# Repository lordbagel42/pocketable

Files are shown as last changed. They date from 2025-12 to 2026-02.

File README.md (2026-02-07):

# Pocketable

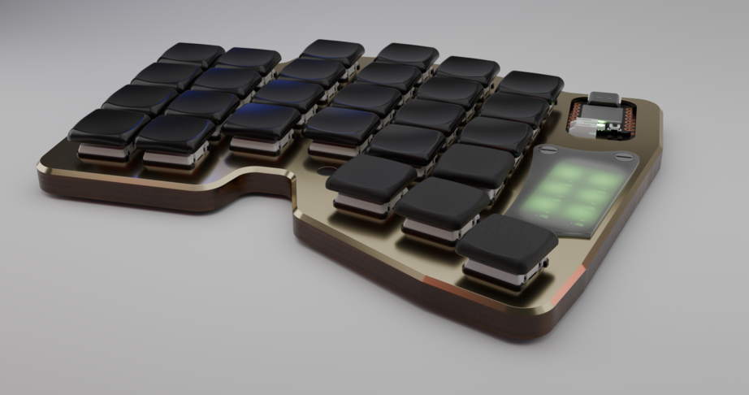
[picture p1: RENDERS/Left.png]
keyboard left half

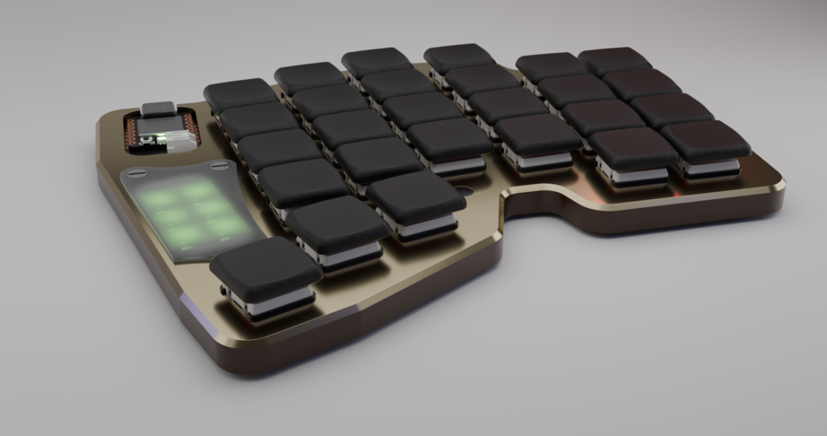
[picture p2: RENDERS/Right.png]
keyboard right half


<sup><sub>ignore the fact that some of the keycaps are shiny and others are matte. blender is not happy with me.</sub></sup>

if a corne and a zsa voyager had a child\_

This project was made for one primary reason: my old split keyboard design kinda sucked to make layouts for. The thumb cluster was horrible. This, however, will function with ZSA Voyager layouts, which are generally shared publicly and well-tested.

This will be for sale eventually. Please reply to [issue 1](https://github.com/lordbagel42/pocketable/issues/1) if you would like to buy one. Cost will be around $240 per keyboard.

## but why?

This keyboards a little special compared to most, for one reason: it's almost all made in-house by me. I'll be machining the brass plate myself along with the wooden base case, plus laser-cutting the acrylic LED cover myself. It's also all hand soldered and one day will have custom keycaps. For now though I've been graciously sponsored with black keycaps.

# BOM

View the BOM at [this google sheet](https://docs.google.com/spreadsheets/d/1JvyBpCuiH7XgFo-gO215HGFeqtSEhnPSUs8fcJy509Q/edit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). Total cost at time of writing this README is ~$250

## more photos :3

heres the pcb design!

silkscreen art will be included for mine, however I won't be showing it in this repo as it contains a lil PII :3

le pcb

## left half schematic



## right half schematic



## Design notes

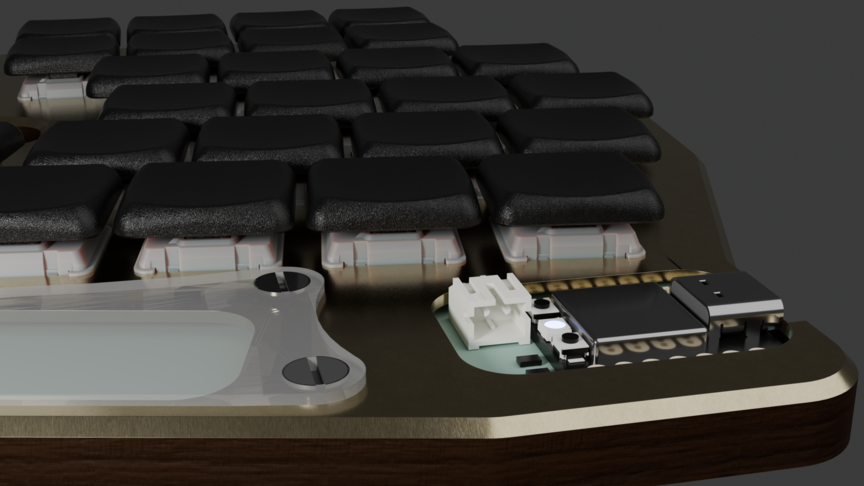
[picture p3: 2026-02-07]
RENDERS/thing.png

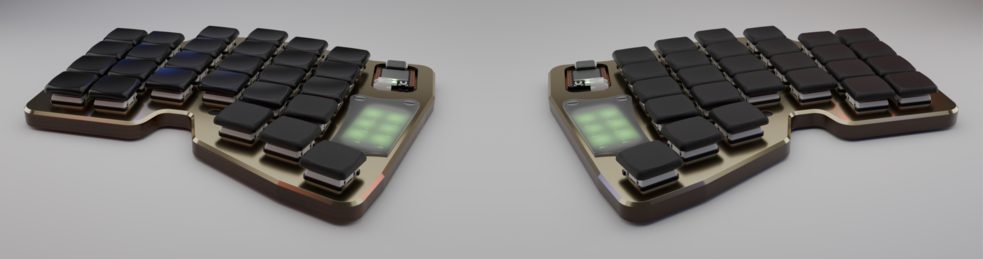
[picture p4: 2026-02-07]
RENDERS/Both maybe.png

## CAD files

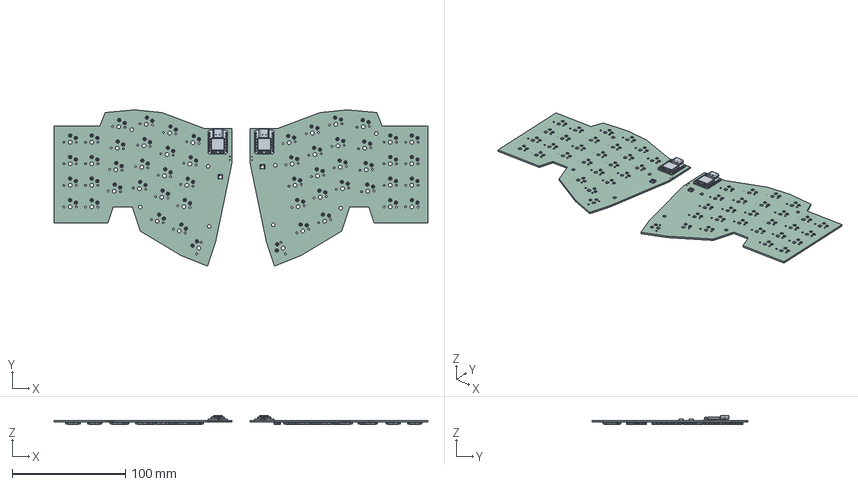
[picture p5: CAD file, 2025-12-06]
PCB/split-keeb-v2.step
330.5 x 138.1 x 8.04 mm
split-keeb-v2 1.1.1 x 2
CON_BM02B-ACHSS x 2
pin x 108
socket x 54
split-keeb-v2_PCB_1
split-keeb-v2_PCB_2

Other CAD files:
CAD/Case Thing.step
MODELS/SOD123_MCC.step
RENDER-FILES/Pocketable.obj
split-keeb-v2-render-edition.step
RENDER-FILES/Render.blend
RENDER-FILES/Render2.blend
RENDER-FILES/Untitled.blend
RENDER-FILES/assets/materials/acrylic_564227e0-b76e-4f32-97c1-0bfcf024c71d/acrylic_405d28f9-2327-4cdb-8ebe-de592a518881.blend
RENDER-FILES/assets/materials/black-plastic_5d077501-2739-44eb-8ed7-a99897d95238/black-plastic_2K_d53818b9-7dfc-4b44-ac51-068fa59820db.blend
RENDER-FILES/assets/materials/black-plastic_e872536a-48ed-4424-ac7b-80dc008e9748/black-plastic_2K_c94cf275-089d-43ee-92c3-5c641194570c.blend
RENDER-FILES/assets/materials/brushed-aluminum_44023395-1cd7-4842-a408-5d7ac18a4476/brushed-aluminum-2_b89e08f7-2682-4f2b-bb34-63eb4a2919d5.blend
RENDER-FILES/assets/materials/brushed-brass_9859c06d-0575-429e-a010-a8d801173d15/brushed-brass_2K_836541c2-a90c-42f0-bd5b-efe868081672.blend
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

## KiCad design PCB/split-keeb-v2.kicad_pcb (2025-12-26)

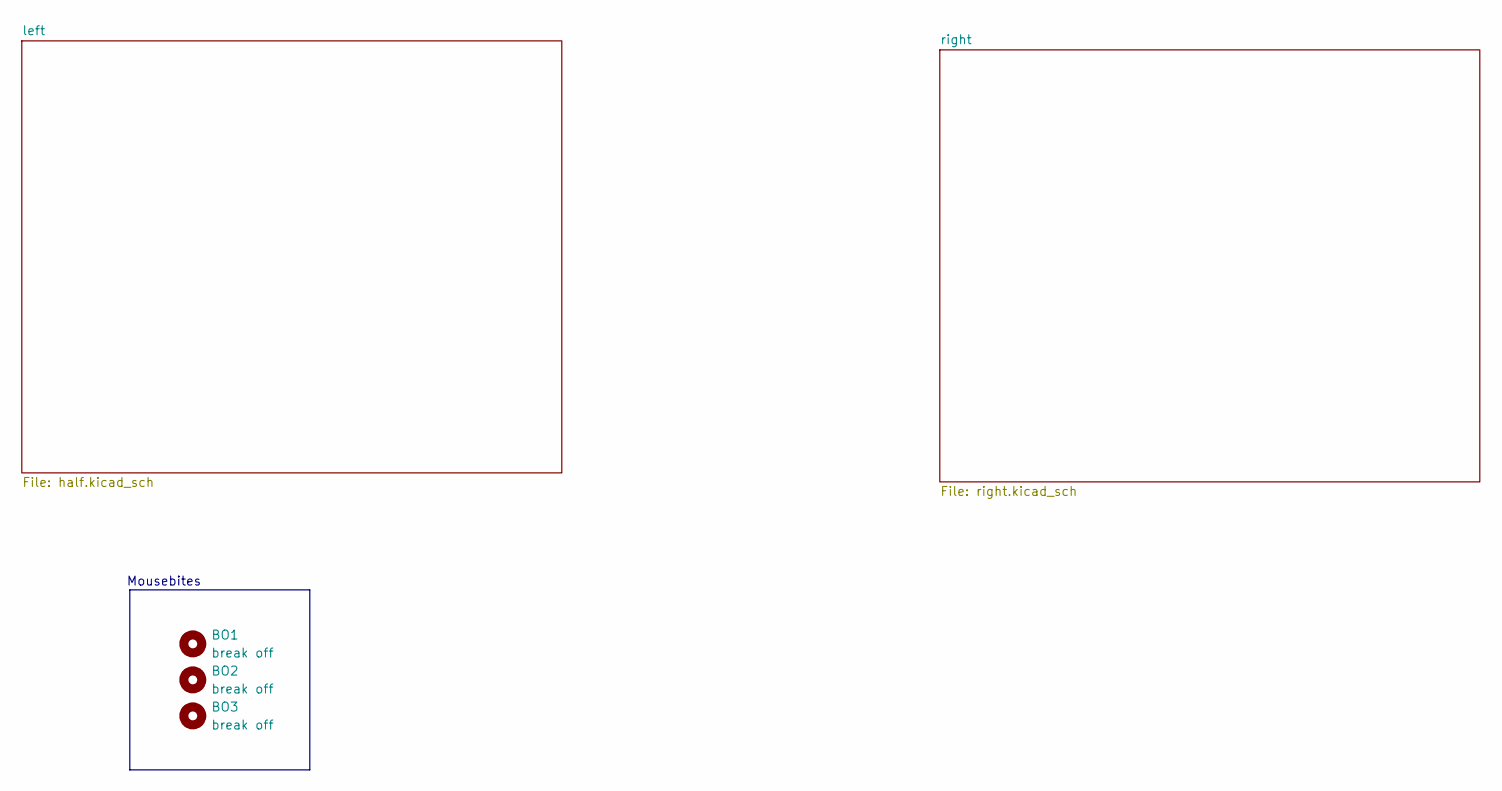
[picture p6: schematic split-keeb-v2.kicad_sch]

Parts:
BO1, BO2, BO3: break off; mouse-bite-5mm-slot

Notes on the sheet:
Mousebites

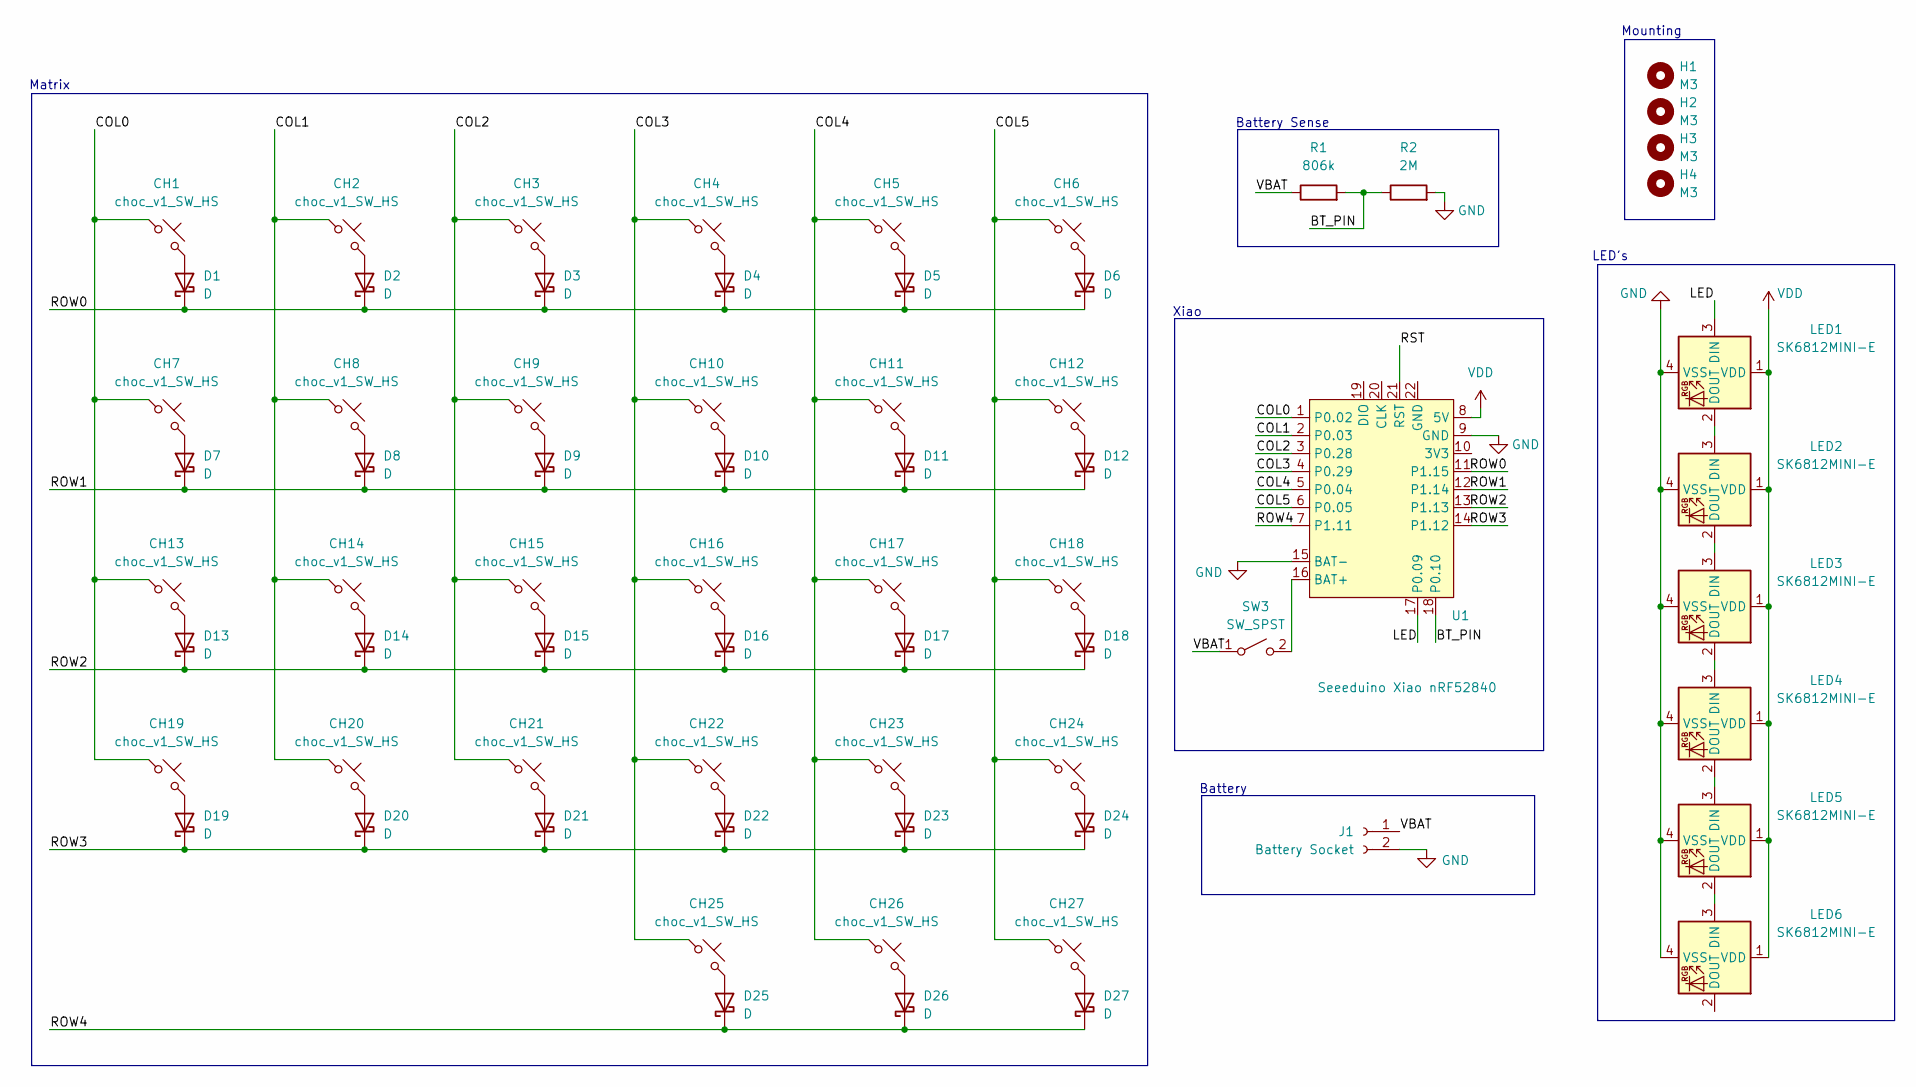
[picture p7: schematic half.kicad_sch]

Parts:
CH1, CH2, CH3, CH4, CH5, CH6, CH7, CH8, CH9, CH10, CH11, CH12, CH13, CH14, CH15, CH16, CH17, CH18, CH19, CH20, CH21, CH22, CH23, CH24, CH25, CH26, CH27: choc_v1_SW_HS; SW_choc_v1_HS_CPG135001S30_1u
D1, D2, D3, D4, D5, D6, D7, D8, D9, D10, D11, D12, D13, D14, D15, D16, D17, D18, D19, D20, D21, D22, D23, D24, D25, D26, D27: D; D_SOD-123
H1, H2, H3, H4: M3; MountingHole_3.2mm_M3
J1: Battery Socket; CON_JST_ACH_BM02B
LED1, LED2, LED3, LED4, LED5, LED6: SK6812MINI-E; LED_6028R
R1: 806k; R_0805_2012Metric
R2: 2M; R_0805_2012Metric
SW3: SW_SPST; SW_SPDT_PCM12
U1: Seeeduino Xiao nRF52840; Xiao_nRF52840_ACH

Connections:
/left/BT_PIN: R1.2, R2.1, U1.18 (P0.10)
/left/COL0: CH1.1, CH7.1, CH13.1, CH19.1, U1.1 (P0.02)
/left/COL1: CH2.1, CH8.1, CH14.1, CH20.1, U1.2 (P0.03)
/left/COL2: CH3.1, CH9.1, CH15.1, CH21.1, U1.3 (P0.28)
/left/COL3: CH4.1, CH10.1, CH16.1, CH22.1, CH25.1, U1.4 (P0.29)
/left/COL4: CH5.1, CH11.1, CH17.1, CH23.1, CH26.1, U1.5 (P0.04)
/left/COL5: CH6.1, CH12.1, CH18.1, CH24.1, CH27.1, U1.6 (P0.05)
/left/LED: LED1.3 (DIN), U1.17 (P0.09)
/left/ROW0: D1.1 (K), D2.1 (K), D3.1 (K), D4.1 (K), D5.1 (K), D6.1 (K), U1.11 (P1.15)
/left/ROW1: D7.1 (K), D8.1 (K), D9.1 (K), D10.1 (K), D11.1 (K), D12.1 (K), U1.12 (P1.14)
/left/ROW2: D13.1 (K), D14.1 (K), D15.1 (K), D16.1 (K), D17.1 (K), D18.1 (K), U1.13 (P1.13)
/left/ROW3: D19.1 (K), D20.1 (K), D21.1 (K), D22.1 (K), D23.1 (K), D24.1 (K), U1.14 (P1.12)
/left/ROW4: D25.1 (K), D26.1 (K), D27.1 (K), U1.7 (P1.11)
/left/RST: U1.21 (RST)
/left/VBAT: J1.1, R1.1, SW3.1 (A)
GND: J1.2, LED1.4 (VSS), LED2.4 (VSS), LED3.4 (VSS), LED4.4 (VSS), LED5.4 (VSS), LED6.4 (VSS), R2.2, U1.9 (GND), U1.15 (BAT-); also elsewhere on the board
unnamed: CH1.2, D1.2 (A)
unnamed: CH2.2, D2.2 (A)
unnamed: CH3.2, D3.2 (A)
unnamed: CH4.2, D4.2 (A)
unnamed: CH5.2, D5.2 (A)
unnamed: CH6.2, D6.2 (A)
unnamed: CH7.2, D7.2 (A)
unnamed: CH8.2, D8.2 (A)
unnamed: CH9.2, D9.2 (A)
unnamed: CH10.2, D10.2 (A)
unnamed: CH11.2, D11.2 (A)
unnamed: CH12.2, D12.2 (A)
unnamed: CH13.2, D13.2 (A)
unnamed: CH14.2, D14.2 (A)
unnamed: CH15.2, D15.2 (A)
unnamed: CH16.2, D16.2 (A)
unnamed: CH17.2, D17.2 (A)
unnamed: CH18.2, D18.2 (A)
unnamed: CH19.2, D19.2 (A)
unnamed: CH20.2, D20.2 (A)
unnamed: CH21.2, D21.2 (A)
unnamed: CH22.2, D22.2 (A)
unnamed: CH23.2, D23.2 (A)
unnamed: CH24.2, D24.2 (A)
unnamed: CH25.2, D25.2 (A)
unnamed: CH26.2, D26.2 (A)
unnamed: CH27.2, D27.2 (A)
unnamed: LED1.2 (DOUT), LED2.3 (DIN)
unnamed: LED2.2 (DOUT), LED3.3 (DIN)
unnamed: LED3.2 (DOUT), LED4.3 (DIN)
unnamed: LED4.2 (DOUT), LED5.3 (DIN)
unnamed: LED5.2 (DOUT), LED6.3 (DIN)
unnamed: SW3.2 (B), U1.16 (BAT+)
VDD: LED1.1 (VDD), LED2.1 (VDD), LED3.1 (VDD), LED4.1 (VDD), LED5.1 (VDD), LED6.1 (VDD), U1.8 (5V); also elsewhere on the board

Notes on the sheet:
Battery Sense
Xiao
LED's
Mounting
Battery
Matrix

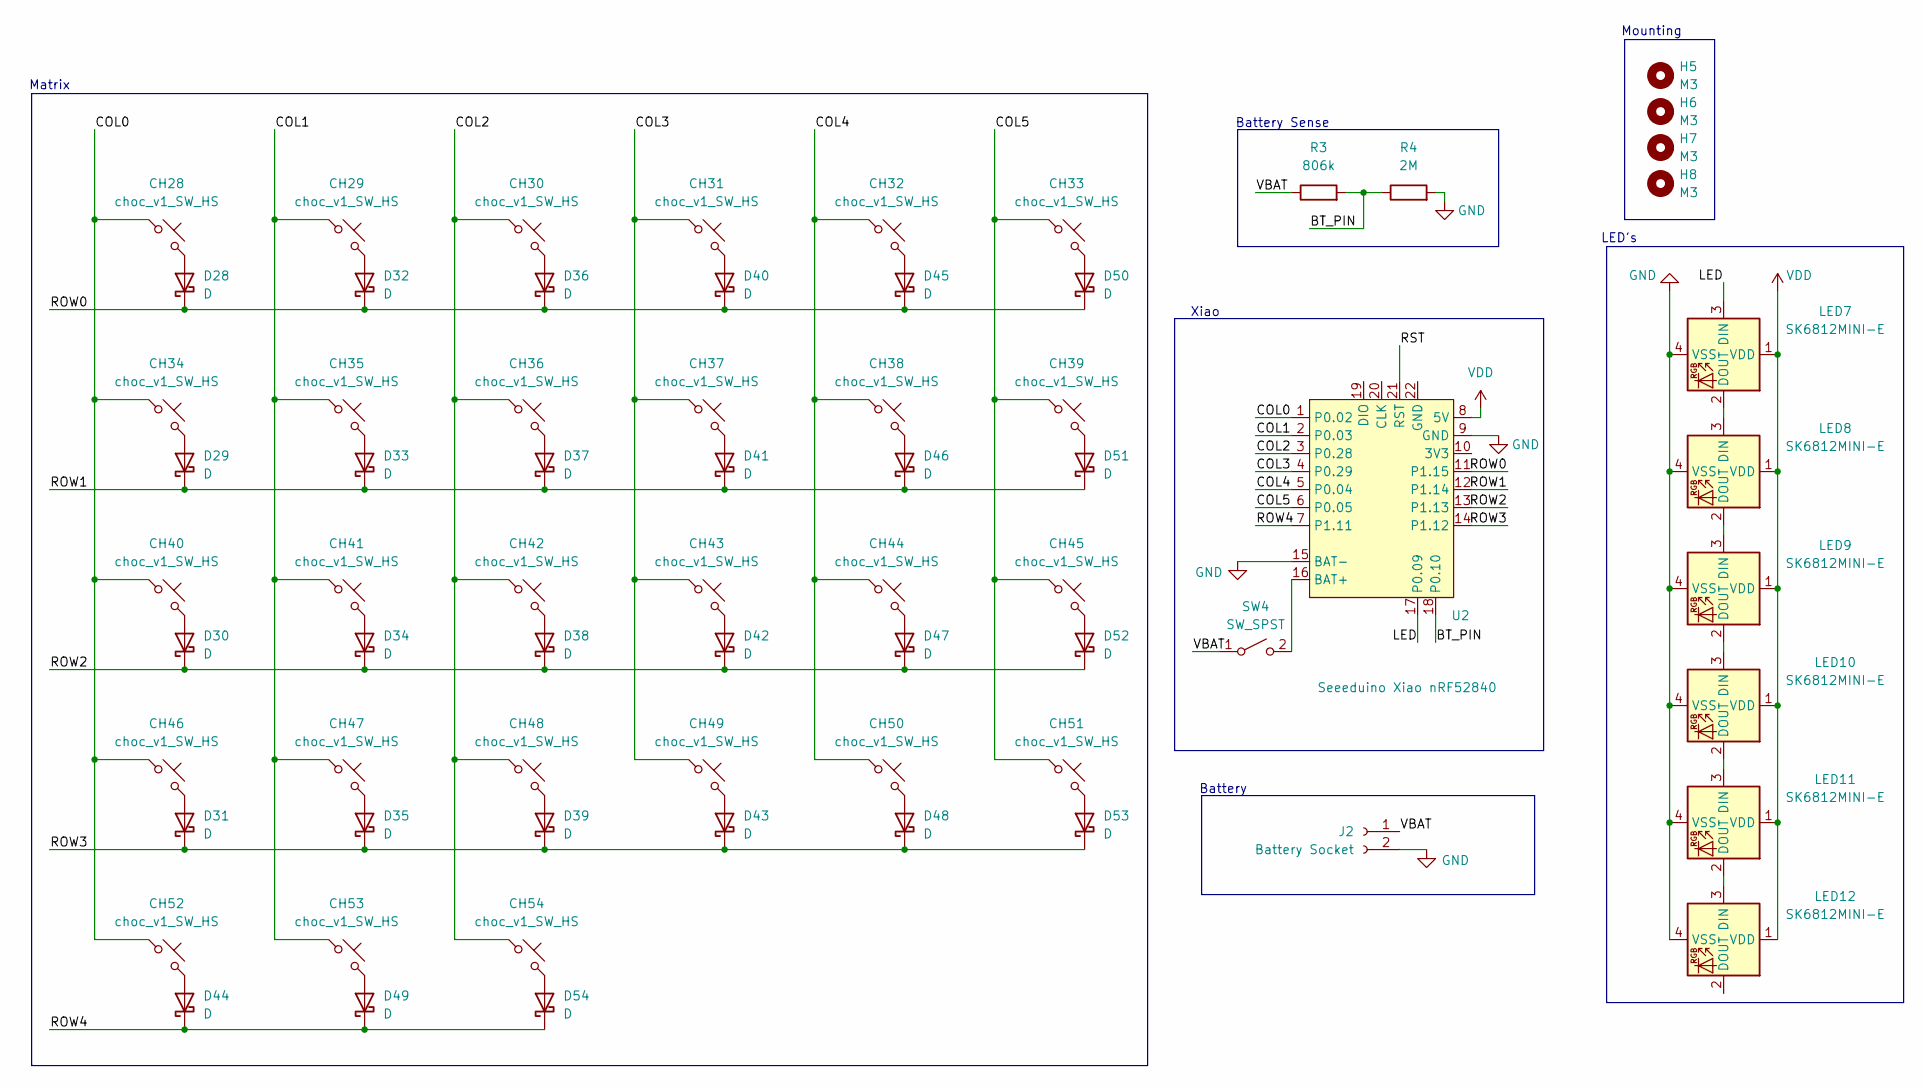
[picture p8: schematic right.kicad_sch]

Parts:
CH28, CH29, CH30, CH31, CH32, CH33, CH34, CH35, CH36, CH37, CH38, CH39, CH40, CH41, CH42, CH43, CH44, CH45, CH46, CH47, CH48, CH49, CH50, CH51, CH52, CH53, CH54: choc_v1_SW_HS; SW_choc_v1_HS_CPG135001S30_1u
D28, D29, D30, D31, D32, D33, D34, D35, D36, D37, D38, D39, D40, D41, D42, D43, D44, D45, D46, D47, D48, D49, D50, D51, D52, D53, D54: D; D_SOD-123
H5, H6, H7, H8: M3; MountingHole_3.2mm_M3
J2: Battery Socket; CON_JST_ACH_BM02B
LED7, LED8, LED9, LED10, LED11, LED12: SK6812MINI-E; LED_6028R
R3: 806k; R_0805_2012Metric
R4: 2M; R_0805_2012Metric
SW4: SW_SPST; SW_SPDT_PCM12
U2: Seeeduino Xiao nRF52840; Xiao_nRF52840_ACH

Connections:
/right/BT_PIN: R3.2, R4.1, U2.18 (P0.10)
/right/COL0: CH28.1, CH34.1, CH40.1, CH46.1, CH52.1, U2.1 (P0.02)
/right/COL1: CH29.1, CH35.1, CH41.1, CH47.1, CH53.1, U2.2 (P0.03)
/right/COL2: CH30.1, CH36.1, CH42.1, CH48.1, CH54.1, U2.3 (P0.28)
/right/COL3: CH31.1, CH37.1, CH43.1, CH49.1, U2.4 (P0.29)
/right/COL4: CH32.1, CH38.1, CH44.1, CH50.1, U2.5 (P0.04)
/right/COL5: CH33.1, CH39.1, CH45.1, CH51.1, U2.6 (P0.05)
/right/LED: LED7.3 (DIN), U2.17 (P0.09)
/right/ROW0: D28.1 (K), D32.1 (K), D36.1 (K), D40.1 (K), D45.1 (K), D50.1 (K), U2.11 (P1.15)
/right/ROW1: D29.1 (K), D33.1 (K), D37.1 (K), D41.1 (K), D46.1 (K), D51.1 (K), U2.12 (P1.14)
/right/ROW2: D30.1 (K), D34.1 (K), D38.1 (K), D42.1 (K), D47.1 (K), D52.1 (K), U2.13 (P1.13)
/right/ROW3: D31.1 (K), D35.1 (K), D39.1 (K), D43.1 (K), D48.1 (K), D53.1 (K), U2.14 (P1.12)
/right/ROW4: D44.1 (K), D49.1 (K), D54.1 (K), U2.7 (P1.11)
/right/RST: U2.21 (RST)
/right/VBAT: J2.1, R3.1, SW4.1 (A)
GND: J2.2, LED7.4 (VSS), LED8.4 (VSS), LED9.4 (VSS), LED10.4 (VSS), LED11.4 (VSS), LED12.4 (VSS), R4.2, U2.9 (GND), U2.15 (BAT-); also elsewhere on the board
unnamed: CH28.2, D28.2 (A)
unnamed: CH34.2, D29.2 (A)
unnamed: CH40.2, D30.2 (A)
unnamed: CH46.2, D31.2 (A)
unnamed: CH29.2, D32.2 (A)
unnamed: CH35.2, D33.2 (A)
unnamed: CH41.2, D34.2 (A)
unnamed: CH47.2, D35.2 (A)
unnamed: CH30.2, D36.2 (A)
unnamed: CH36.2, D37.2 (A)
unnamed: CH42.2, D38.2 (A)
unnamed: CH48.2, D39.2 (A)
unnamed: CH31.2, D40.2 (A)
unnamed: CH37.2, D41.2 (A)
unnamed: CH43.2, D42.2 (A)
unnamed: CH49.2, D43.2 (A)
unnamed: CH52.2, D44.2 (A)
unnamed: CH32.2, D45.2 (A)
unnamed: CH38.2, D46.2 (A)
unnamed: CH44.2, D47.2 (A)
unnamed: CH50.2, D48.2 (A)
unnamed: CH53.2, D49.2 (A)
unnamed: CH33.2, D50.2 (A)
unnamed: CH39.2, D51.2 (A)
unnamed: CH45.2, D52.2 (A)
unnamed: CH51.2, D53.2 (A)
unnamed: CH54.2, D54.2 (A)
unnamed: LED7.2 (DOUT), LED8.3 (DIN)
unnamed: LED8.2 (DOUT), LED9.3 (DIN)
unnamed: LED9.2 (DOUT), LED10.3 (DIN)
unnamed: LED10.2 (DOUT), LED11.3 (DIN)
unnamed: LED11.2 (DOUT), LED12.3 (DIN)
unnamed: SW4.2 (B), U2.16 (BAT+)
VDD: LED7.1 (VDD), LED8.1 (VDD), LED9.1 (VDD), LED10.1 (VDD), LED11.1 (VDD), LED12.1 (VDD), U2.8 (5V); also elsewhere on the board

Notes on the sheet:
LED's
Battery Sense
Xiao
Mounting
Battery
Matrix

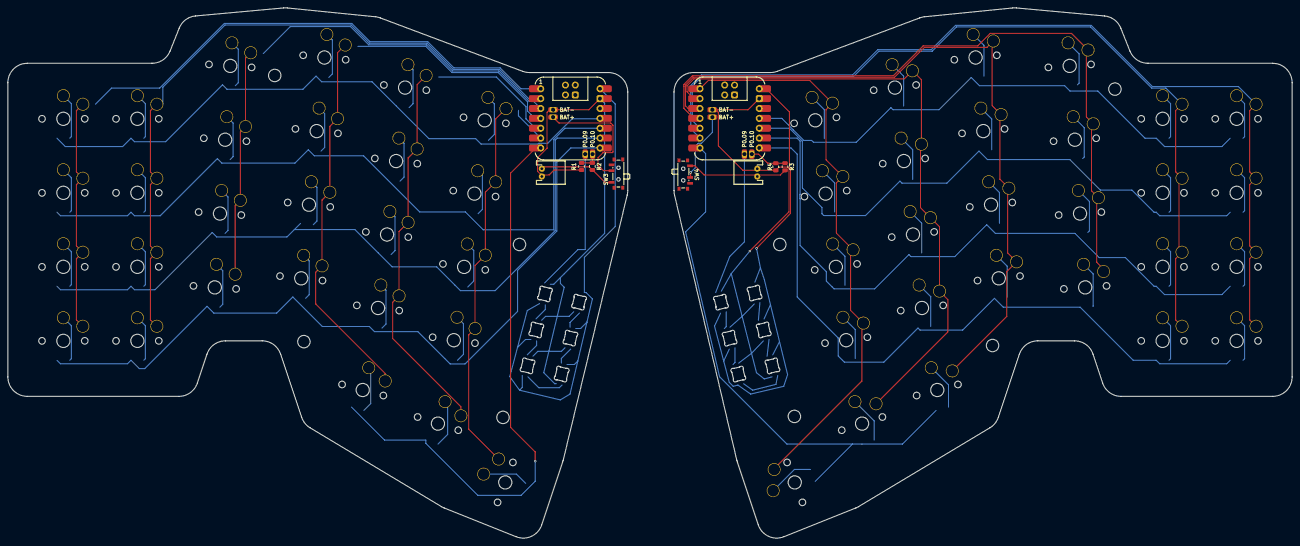
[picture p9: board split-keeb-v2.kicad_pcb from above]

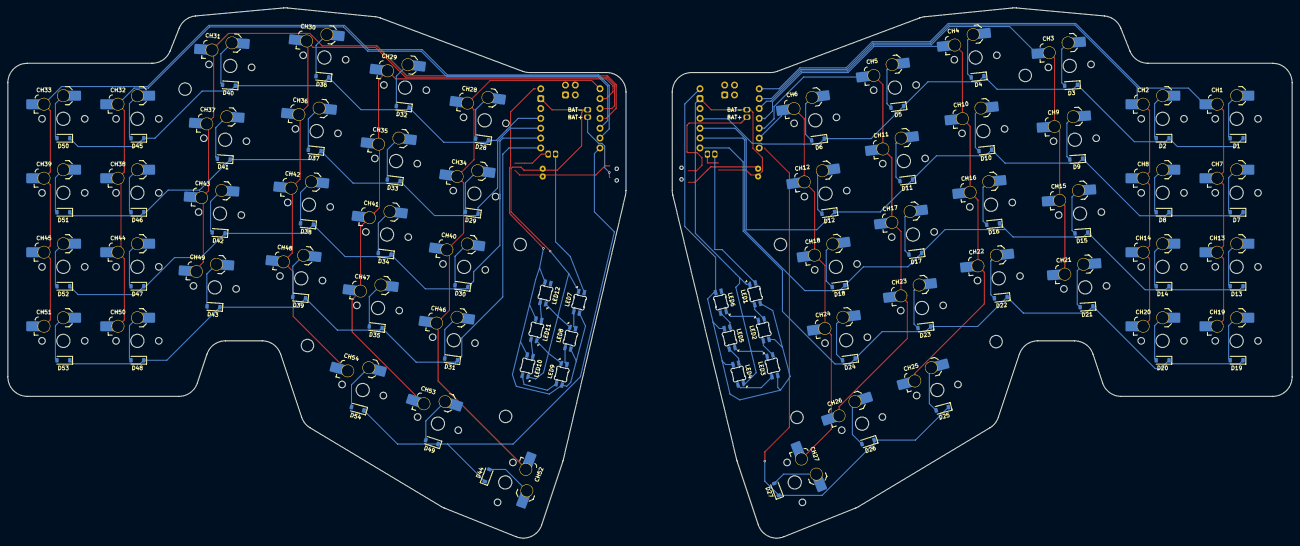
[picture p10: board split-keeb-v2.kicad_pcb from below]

Board: 2 copper layers, 330.5 x 136.5 mm, 138 parts (120 on the bottom side), 96 nets.

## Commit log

2025-12-06 bom, readme ish
    [half.kicad_sch, left.kicad_sch, right.kicad_sch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]
2025-12-06 oopsies forgot to add the CAD lol
    [Case Thing.step]
2025-12-06 we ain't getting to prototype with this one
    [Case Thing.step, half.kicad_sch, left.kicad_sch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]
2025-12-26 lfs here we go
    [Pocketable.obj, Render.blend, Render2.blend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]
2026-01-15 include schematic pics
2026-02-07 fix RENDERS/
    [Case Thing.step, Pocketable.obj, Render.blend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]
2026-02-07 Add PNG and STEP files to Git LFS tracking
    Amp-Thread-ID: https://ampcode.com/threads/T-f1c5a740-9b84-4d3c-b824-d55490b994a5
2026-02-07 Remove git lfs and compress render images
    Amp-Thread-ID: https://ampcode.com/threads/T-019c37a1-df57-7555-86bd-4a8d9f45d67f
